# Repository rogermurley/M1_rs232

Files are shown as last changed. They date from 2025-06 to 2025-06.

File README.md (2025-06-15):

# M1_rs232
RS-232 interface board for the TRS-80 Model I Expansion Interface, version 2.1

ver2 1onwhite

### If you would like to purchase turnkey assembled and tested units, or bare PCBs, please visit my site at https://byteshiftmusic.com/trs-80-model-i-rs-232-interface-re-creation/

I also have available a PCB for adapting the 40-pin edge card (J1) on the Expansion Interface to an IDC26 header, so that a standard PC parallel port DB25 pigtail can be used. Please see the link above for those, as well.

I created this design partly out of necessity, as original Radio Shack serial interfaces are scarce, and partly as a project to learn KiCad.

This design replicates the operation of the original board, ensuring compatibility with existing Model I software. Hardware-wise, there are a few differences:
  1. SMT components are used wherever possible, to minimize cost
  2. Sense switch (DIP switch configuration) functionality is removed, so that the interface must be configured via software
  3. The TERM/COMM switch has been removed. The unit is configured in TERM (DTE) mode, and an external null-modem adapter must be used if operation as a DCE device is required.
  4. IC selection eliminated the need for +12/-12/-5 supply rails. +5V is the only supply needed.

Version 2.1 fixes a nasty error which caused the line driver (U9) to be in permanent shutdown mode, fixes some minor mechanical interference between the PCB and the expansion interface's chassis, and adds some quality of life enhancements, such as:
 1. A jumper for RS-232 TX/RX loopback was added for ease of testing
 2. A breakout header for TTL-level TX and RX was added, for ease in interfacing to an ESP8266 running [WiFiModem firmware](https://github.com/dhansel/WifiModem)
 3. A breakout header for +5VDC and GND was added for powering the previously mentioned ESP8266
 4. A jumper for disabling the RS-232 transceiver was added, for use when using an internal TTL-level device

BOM notes:
  1. J1 is PCB fingers on the underside of the board, which press-fit against the Expansion Interface add-on connector.
  2. J2, J3, J4, and J5 are standard 2.54mm pitch single row headers, 11 pins in total
  3. Y1 must be an AT-cut series type crystal with an ESR of <= 50 ohms in order to function properly with the 8116 baud rate generator.
  4. U1 and U2 must be purchased used or as old stock. Ebay is a good source.
  5. U2's COM8116 can be substituted with a Western Digital WD1943. Please ensure that the IC that you purchase is the variant (typically with a -00 suffix) which uses a 5.0688 MHz crystal and produces a 16x baud clock. If you have the -05 variant which uses a 4.9152 MHz crystal, this may work by substituting the proper crystal for Y1, but this has not been tested. The -06 variant, which generates a 32x baud clock, will NOT work with this UART.

ver2 1rendertop
ver2 1renderbottom

This project is released under the [CERN Open Hardware Licence Version 2 - Strongly Reciprocal](https://gitlab.com/ohwr/project/cernohl/-/blob/master/licence_texts/cern_ohl_w_v2.txt?ref_type=heads). Copyright 2025 Roger Murley.

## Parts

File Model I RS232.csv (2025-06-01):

Reference | Qty | Value | DNP | Exclude from BOM | Exclude from Board | Footprint | Datasheet
C1,C2,C3,C5,C6,C7,C8,C9,C11,C12,C13,C14 | 12 | 0.1uF |  |  |  | Capacitor_SMD:C_0805_2012Metric_Pad1.18x1.45mm_HandSolder | ~
C4,C10 | 2 | 0.47uF |  |  |  | Capacitor_SMD:C_0805_2012Metric_Pad1.18x1.45mm_HandSolder | ~
C15 | 1 | 4.7uF |  |  |  | Capacitor_SMD:C_0805_2012Metric_Pad1.18x1.45mm_HandSolder | ~
J1 | 1 | ~ |  | Excluded from BOM |  | Byteshift_Library:TRS-80 M1 EI_ADDON_42P_CONN
J2 | 1 | Conn_01x03_Pin |  |  |  | Connector_PinHeader_2.54mm:PinHeader_1x03_P2.54mm_Vertical | ~
J3 | 1 | Conn_01x04_Pin |  |  |  | Connector_PinHeader_2.54mm:PinHeader_1x04_P2.54mm_Vertical | ~
J4,J5 | 2 | Conn_01x02_Pin |  |  |  | Connector_PinHeader_2.54mm:PinHeader_1x02_P2.54mm_Vertical | ~
R1 | 1 | 4.7K |  |  |  | Resistor_SMD:R_0805_2012Metric_Pad1.20x1.40mm_HandSolder | ~
U1 | 1 | HD6402 |  |  |  | Package_DIP:DIP-40_W15.24mm_Socket_LongPads
U2 | 1 | COM8116 |  |  |  | Package_DIP:DIP-18_W7.62mm_Socket_LongPads
U3 | 1 | 74LS155 |  |  |  | Package_SO:SOIC-16_3.9x9.9mm_P1.27mm | http://www.ti.com/lit/gpn/sn74LS155
U4 | 1 | 74LS04 |  |  |  | Package_SO:SOIC-14_3.9x8.7mm_P1.27mm | http://www.ti.com/lit/gpn/sn74LS04
U5 | 1 | 74LS00 |  |  |  | Package_SO:SOIC-14_3.9x8.7mm_P1.27mm | http://www.ti.com/lit/gpn/sn74ls00
U6 | 1 | 74LS244 |  |  |  | Package_SO:SOIC-20W_7.5x12.8mm_P1.27mm | http://www.ti.com/lit/ds/symlink/sn74ls244.pdf
U7 | 1 | 74LS367 |  |  |  | Package_SO:SOIC-16_3.9x9.9mm_P1.27mm | http://www.ti.com/lit/gpn/sn74LS367
U8 | 1 | 74LS174 |  |  |  | Package_SO:SOIC-16_3.9x9.9mm_P1.27mm | http://www.ti.com/lit/gpn/sn74LS174
U9 | 1 | SP3243ECA-L/TR |  |  |  | Package_SO:SSOP-28_5.3x10.2mm_P0.65mm | SP3243ECA-L/TR
U10 | 1 | 74LS08 |  |  |  | Package_SO:SOIC-14_3.9x8.7mm_P1.27mm | http://www.ti.com/lit/gpn/sn74LS08
Y1 | 1 | 5.0688 MHz |  |  |  | Crystal:Crystal_HC49-U_Horizontal | ~

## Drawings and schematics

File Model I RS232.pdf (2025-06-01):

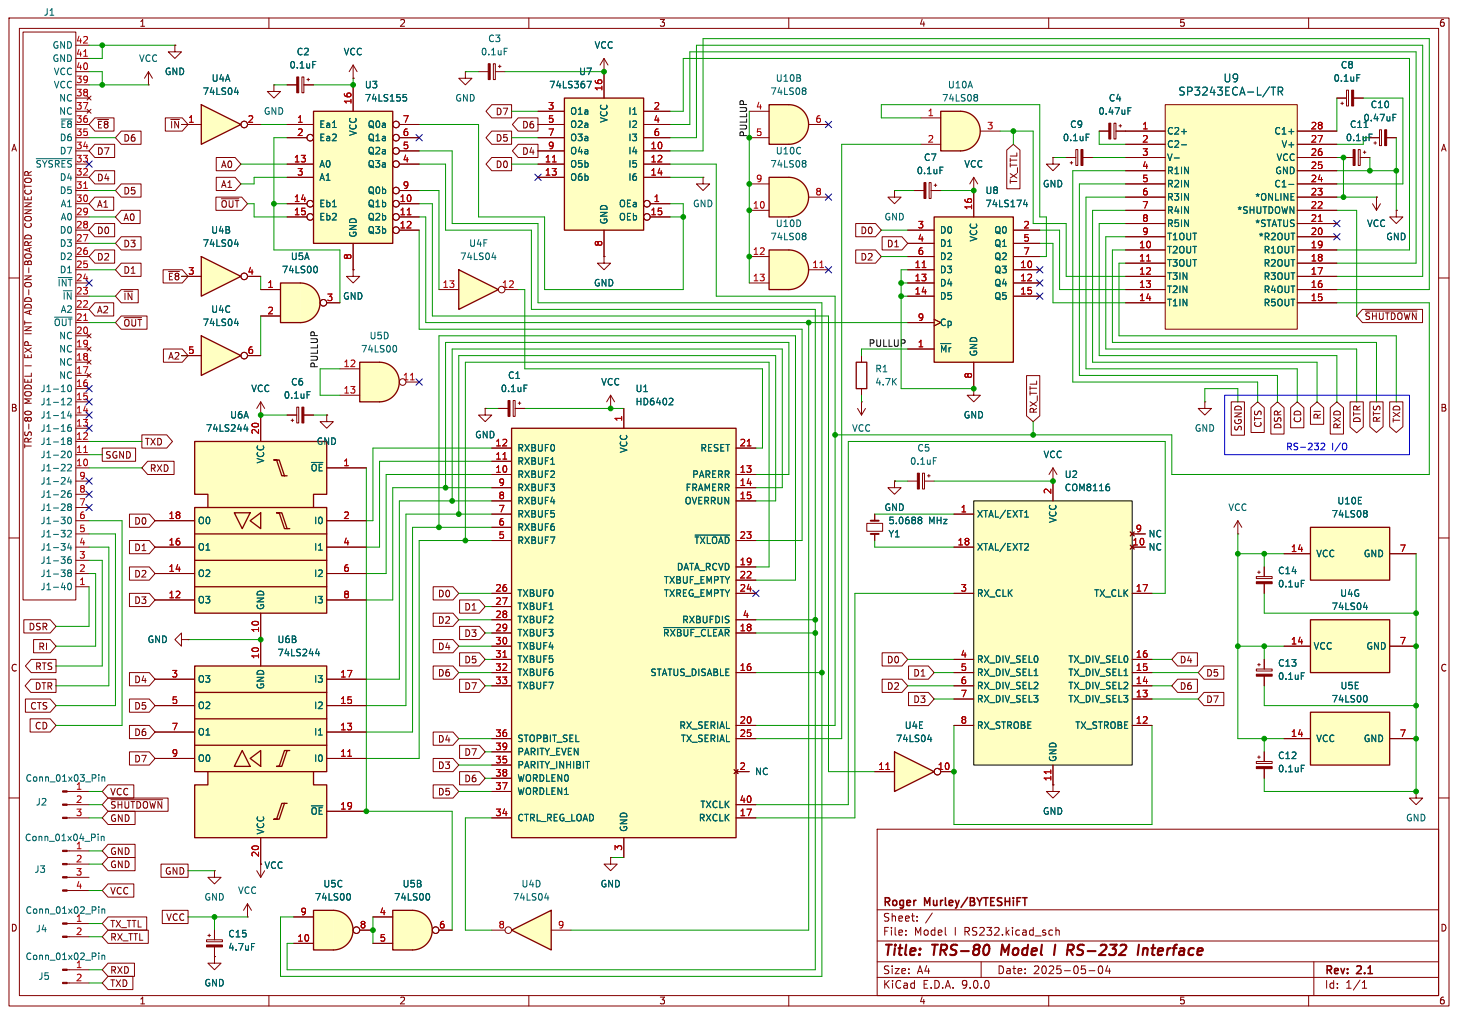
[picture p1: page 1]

2 GND 11 NC 9 NC 10 TX_CLK 17 TX_DIV_SEL0 16 TX_DIV_SEL1 15 TX_DIV_SEL2 14 TX_DIV_SEL3 13 TX_STROBE 12 U2 COM8116 GND GND GND

3 NC 2 RESET 21 PARERR 13 FRAMERR 14 OVERRUN 15 ~{TXLOAD}23 DATA_RCVD 19 TXBUF_EMPTY 22 TXREG_EMPTY 24 RXBUFDIS 4 ~{RXBUF_CLEAR}18 STATUS_DISABLE 16 RX_SERIAL 20 TX_SERIAL 25 TXCLK 40 RXCLK 17 U1 HD6402 GND

3 NC 2 RESET 21 PARERR 13 FRAMERR 14 OVERRUN 15 ~{TXLOAD}23 DATA_RCVD 19 TXBUF_EMPTY 22 TXREG_EMPTY 24 RXBUFDIS 4 ~{RXBUF_CLEAR}18 STATUS_DISABLE 16 RX_SERIAL 20 TX_SERIAL 25 TXCLK 40 RXCLK 17 GND GND

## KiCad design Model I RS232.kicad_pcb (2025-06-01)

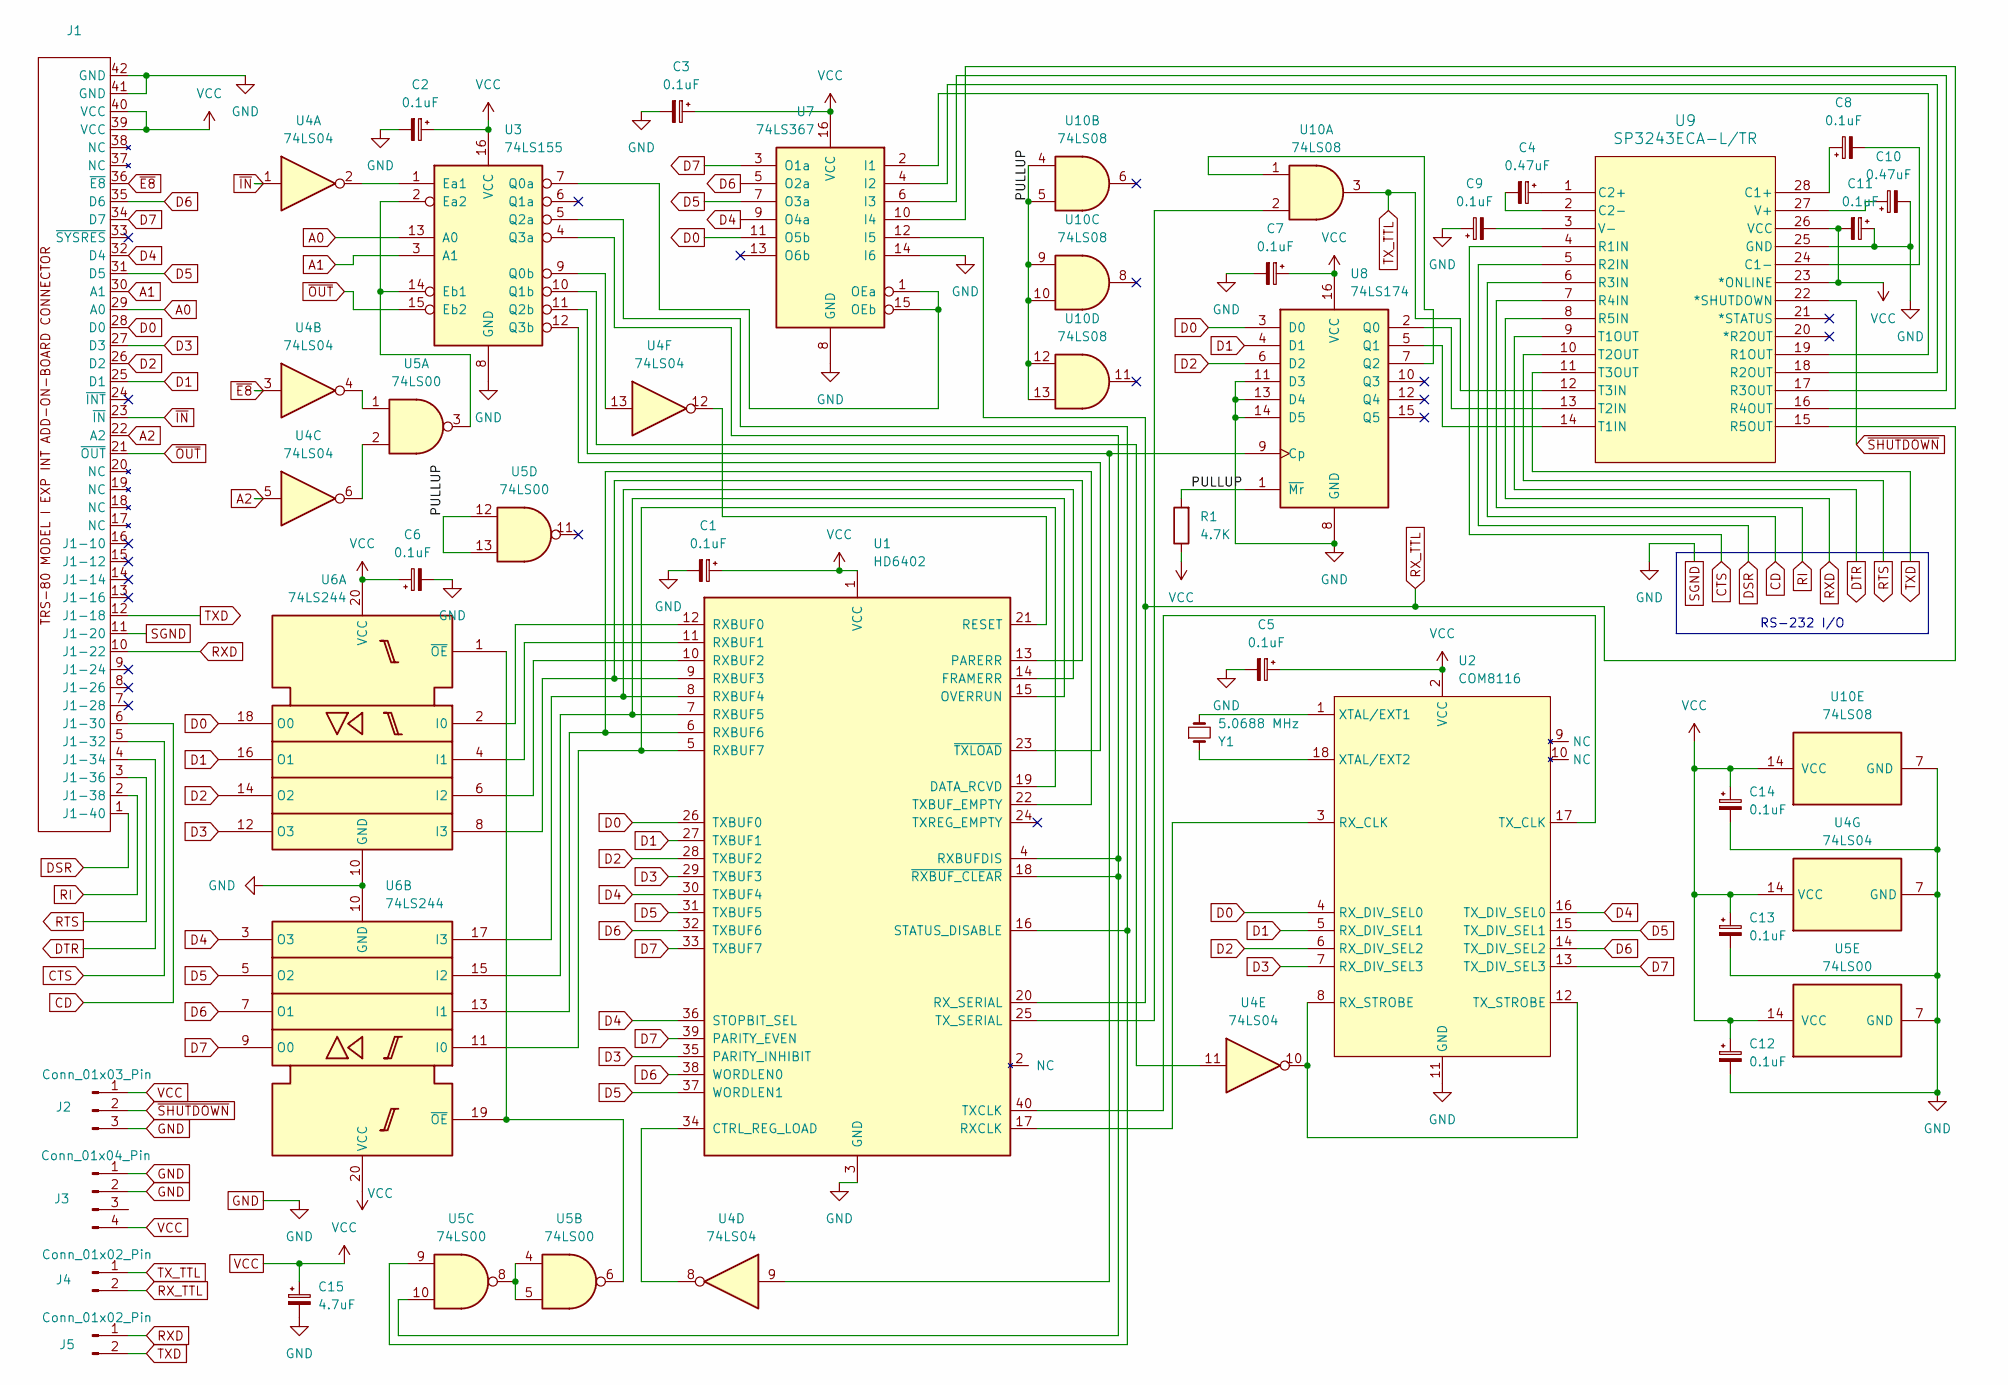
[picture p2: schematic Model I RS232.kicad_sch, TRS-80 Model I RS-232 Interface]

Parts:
C1, C2, C3, C5, C6, C7, C8, C9, C11, C12, C13, C14: 0.1uF; C_0805_2012Metric_Pad1.18x1.45mm_HandSolder
C4, C10: 0.47uF; C_0805_2012Metric_Pad1.18x1.45mm_HandSolder
C15: 4.7uF; C_0805_2012Metric_Pad1.18x1.45mm_HandSolder
J1: TRS-80 M1 EI_ADDON_42P_CONN
J2: Conn_01x03_Pin; PinHeader_1x03_P2.54mm_Vertical
J3: Conn_01x04_Pin; PinHeader_1x04_P2.54mm_Vertical
J4, J5: Conn_01x02_Pin; PinHeader_1x02_P2.54mm_Vertical
R1: 4.7K; R_0805_2012Metric_Pad1.20x1.40mm_HandSolder
U1: HD6402; DIP-40_W15.24mm_Socket_LongPads
U2: COM8116; DIP-18_W7.62mm_Socket_LongPads
U3: 74LS155; SOIC-16_3.9x9.9mm_P1.27mm
U4: 74LS04; SOIC-14_3.9x8.7mm_P1.27mm
U5: 74LS00; SOIC-14_3.9x8.7mm_P1.27mm
U6: 74LS244; SOIC-20W_7.5x12.8mm_P1.27mm
U7: 74LS367; SOIC-16_3.9x9.9mm_P1.27mm
U8: 74LS174; SOIC-16_3.9x9.9mm_P1.27mm
U9: SP3243ECA-L/TR; SSOP-28_5.3x10.2mm_P0.65mm
U10: 74LS08; SOIC-14_3.9x8.7mm_P1.27mm
Y1: 5.0688 MHz; Crystal_HC49-U_Horizontal

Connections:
/PULLUP: R1.2, U5.12, U5.13, U8.1 (~Mr), U10.4, U10.5, U10.9, U10.10, U10.12, U10.13
A0: J1.29 (A0), U3.13 (A0)
A1: J1.30 (A1), U3.3 (A1)
A2: J1.22 (A2), U4.5
CD: J1.6 (J1-30), U9.6 (R3IN)
CTS: J1.5 (J1-32), U9.4 (R1IN)
D0: J1.28 (D0), U1.26 (TXBUF0), U2.4 (RX_DIV_SEL0), U6.18 (O0), U7.11 (O5b), U8.3 (D0)
D1: J1.25 (D1), U1.27 (TXBUF1), U2.5 (RX_DIV_SEL1), U6.16 (O1), U8.4 (D1)
D2: J1.26 (D2), U1.28 (TXBUF2), U2.6 (RX_DIV_SEL2), U6.14 (O2), U8.6 (D2)
D3: J1.27 (D3), U1.29 (TXBUF3), U1.35 (PARITY_INHIBIT), U2.7 (RX_DIV_SEL3), U6.12 (O3)
D4: J1.32 (D4), U1.30 (TXBUF4), U1.36 (STOPBIT_SEL), U2.16 (TX_DIV_SEL0), U6.3 (O3), U7.9 (O4a)
D5: J1.31 (D5), U1.31 (TXBUF5), U1.37 (WORDLEN1), U2.15 (TX_DIV_SEL1), U6.5 (O2), U7.7 (O3a)
D6: J1.35 (D6), U1.32 (TXBUF6), U1.38 (WORDLEN0), U2.14 (TX_DIV_SEL2), U6.7 (O1), U7.5 (O2a)
D7: J1.34 (D7), U1.33 (TXBUF7), U1.39 (PARITY_EVEN), U2.13 (TX_DIV_SEL3), U6.9 (O0), U7.3 (O1a)
DSR: J1.1 (J1-40), U9.5 (R2IN)
DTR: J1.4 (J1-34), U9.9 (T1OUT)
GND: C1.2, C2.2, C3.2, C5.2, C6.2, C7.2, C9.1, C10.2, C11.1, C12.2, C13.2, C14.2, C15.2, J1.11 (J1-20), J1.41 (GND), J1.42 (GND), J2.3, J3.1, J3.2, U1.3 (GND), U2.11 (GND), U3.8 (GND), U4.7 (GND), U5.7 (GND), U6.10 (GND), U7.8 (GND), U7.14 (I6), U8.8 (GND), U8.11 (D3), U8.13 (D4), U8.14 (D5), U9.25 (GND), U10.7 (GND)
unnamed: U1.34 (CTRL_REG_LOAD), U4.8
unnamed: U1.5 (RXBUF7), U1.19 (DATA_RCVD), U6.11 (I0)
unnamed: U1.8 (RXBUF4), U1.14 (FRAMERR), U6.17 (I3)
unnamed: U1.7 (RXBUF5), U1.15 (OVERRUN), U6.15 (I2)
unnamed: U1.9 (RXBUF3), U1.13 (PARERR), U6.8 (I3)
unnamed: U1.21 (RESET), U4.12
unnamed: U1.12 (RXBUF0), U6.2 (I0)
unnamed: U1.11 (RXBUF1), U6.4 (I1)
unnamed: U1.10 (RXBUF2), U6.6 (I2)
unnamed: U1.6 (RXBUF6), U1.22 (TXBUF_EMPTY), U6.13 (I1)
unnamed: U1.4 (RXBUFDIS), U1.18 (~RXBUF_CLEAR), U3.4 (Q3a), U5.10
unnamed: U1.17 (RXCLK), U2.3 (RX_CLK)
unnamed: U1.16 (STATUS_DISABLE), U3.5 (Q2a), U5.9
unnamed: U1.40 (TXCLK), U2.17 (TX_CLK)
unnamed: U1.25 (TX_SERIAL), U10.2
unnamed: U1.23 (~TXLOAD), U3.12 (Q3b)
unnamed: U2.8 (RX_STROBE), U2.12 (TX_STROBE), U4.10
unnamed: U2.1 (XTAL/EXT1), Y1.2
unnamed: U2.18 (XTAL/EXT2), Y1.1
unnamed: U3.1 (Ea1), U4.2
unnamed: U3.2 (Ea2), U3.14 (Eb1), U5.3
unnamed: U3.7 (Q0a), U7.1 (OEa), U7.15 (OEb)
unnamed: U3.9 (Q0b), U4.13
unnamed: U3.10 (Q1b), U4.11
unnamed: U3.11 (Q2b), U4.9, U8.9 (Cp)
unnamed: U4.4, U5.1
unnamed: U4.6, U5.2
unnamed: U5.4, U5.5, U5.8
unnamed: U5.6, U6.1 (~OE), U6.19 (~OE)
unnamed: U7.2 (I1), U9.19 (R1OUT)
unnamed: U7.4 (I2), U9.18 (R2OUT)
unnamed: U7.6 (I3), U9.17 (R3OUT)
unnamed: U7.10 (I4), U9.16 (R4OUT)
unnamed: U8.2 (Q0), U9.13 (T2IN)
unnamed: U8.5 (Q1), U9.14 (T1IN)
unnamed: U8.7 (Q2), U10.1
unnamed: C8.1, U9.28 (C1+)
unnamed: C8.2, U9.24 (C1-)
unnamed: C4.1, U9.1 (C2+)
unnamed: C4.2, U9.2 (C2-)
unnamed: C10.1, U9.27 (V+)
unnamed: C9.2, U9.3 (V-)
RI: J1.2 (J1-38), U9.7 (R4IN)
RTS: J1.3 (J1-36), U9.10 (T2OUT)
RXD: J1.10 (J1-22), J5.1, U9.8 (R5IN)
RX_TTL: J4.2, U1.20 (RX_SERIAL), U7.12 (I5), U9.15 (R5OUT)
TXD: J1.12 (J1-18), J5.2, U9.11 (T3OUT)
TX_TTL: J4.1, U9.12 (T3IN), U10.3
VCC: C1.1, C2.1, C3.1, C5.1, C6.1, C7.1, C11.2, C12.1, C13.1, C14.1, C15.1, J1.39 (VCC), J1.40 (VCC), J2.1, J3.4, R1.1, U1.1 (VCC), U2.2 (VCC), U3.16 (VCC), U4.14 (VCC), U5.14 (VCC), U6.20 (VCC), U7.16 (VCC), U8.16 (VCC), U9.23 (*ONLINE), U9.26 (VCC), U10.14 (VCC)
~E8: J1.36 (~E8), U4.3
~IN: J1.23 (~IN), U4.1
~OUT: J1.21 (~OUT), U3.15 (Eb2)
~SHUTDOWN: J2.2, U9.22 (*SHUTDOWN)

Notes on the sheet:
RS-232 I/O

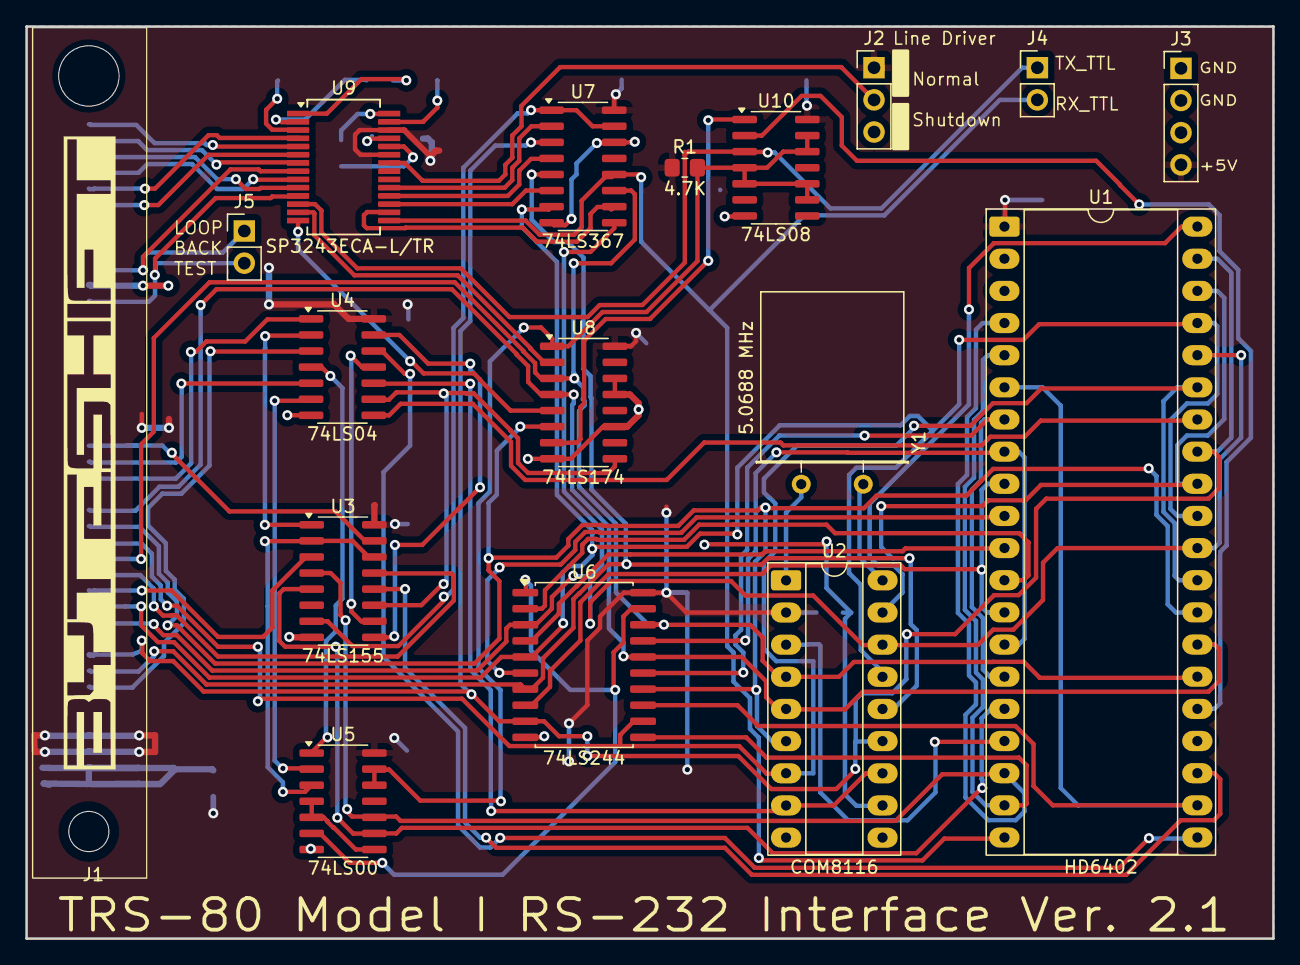
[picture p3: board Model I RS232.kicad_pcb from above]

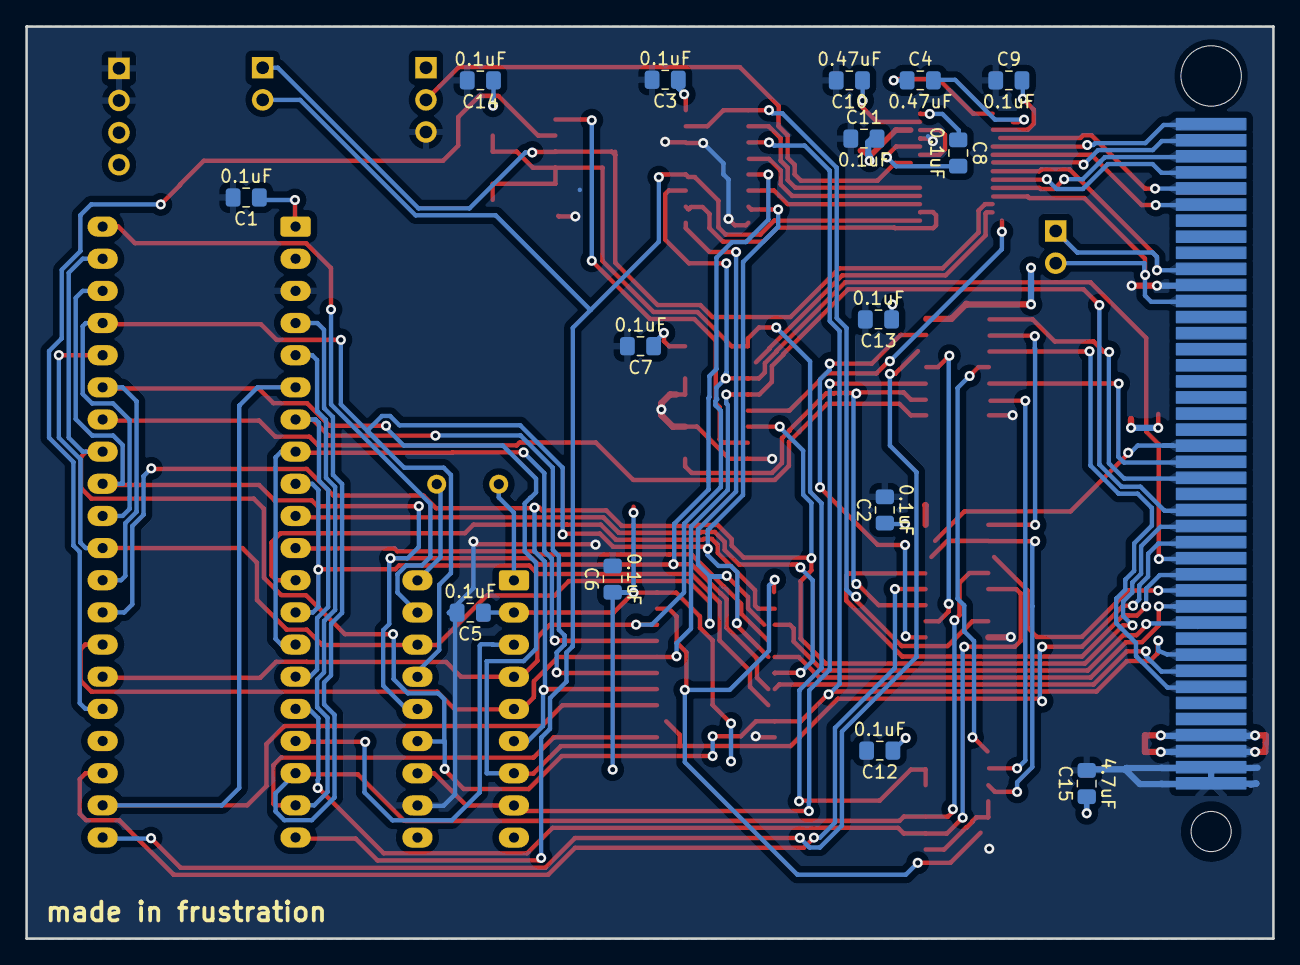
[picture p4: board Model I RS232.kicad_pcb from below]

Board: 2 copper layers, 98.5 x 72.1 mm, 32 parts (15 on the bottom side), 70 nets.

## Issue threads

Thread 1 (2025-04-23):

Better idea of actual parts?

tuctboh, 2025-04-23:
Hi,

Trying to build this (Would like to talk about distributing it) and having some issues identifying proper parts. Is there a parts list that you actually used?

Thanks, Tuc

tuctboh, 2025-04-30:
Bump

tuctboh, 2025-05-06:
Bump

rogermurley, 2025-05-07:
The BOM is in the repo. Also, as noted in the readme, this version has errors and should not be built in its current state.
I also do not appreceiate your stalker-ish behavior towards me. In fact, this has made me reconsider releasing future versions at all.

Closed 2025-05-07.

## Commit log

2025-03-15 Update README.md
    Added BOM notes
2025-03-17 Add files via upload
    trimmed PCB size a bit to clear support post
    [Model I RS232.kicad_pcb]
2025-03-17 Add files via upload
    Gerbers recreated after PCB changes
    [Model I RS232-B_Cu.gbr, Model I RS232-B_Mask.gbr, Model I RS232-B_Silkscreen.gbr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]
2025-04-05 Delete Model I RS232 Schematic.pdf
    Changing filenames to match KiCAD output
2025-04-05 Delete Model I RS232 BOM.csv
    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
    [Model I RS232 BOM.csv]
2025-04-05 Delete Model I RS232 legacy BOM.csv
    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
    [Model I RS232 legacy BOM.csv]
2025-04-05 Add files via upload
    Update schematic and PCB to version 1.1 -- 05 April 2025
    1. change PCB footprint to eliminate mechanical interference with mounting post
    2. modify footprint of J1 pads to fit more closely
    3. fix schematic error causing U9 to be in permanent shutdown mode
    4. Clean up some very ugly routing
    5. Change version information on silkscreen
    6. embed silkscreen logo as footprint to fix missing font error
    [Model I RS232-B_Cu.gbr, Model I RS232-B_Mask.gbr, Model I RS232-B_Silkscreen.gbr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]
2025-04-05 Update README.md
    Added lower-side PCB render
2025-04-06 Add files via upload
    Updated local footprint for J1
2025-06-01 Update README.md for board version 2.1
2025-06-10 Update README.md
    added info on U2 substitution, and noted that bare PCBs are available for sale
